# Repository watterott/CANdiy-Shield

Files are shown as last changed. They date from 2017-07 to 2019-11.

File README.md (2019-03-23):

# CANdiy-Shield
The CANdiy-Shield is a plug-on module for Arduino with CAN-Bus (Controller Area Network) connectivity.

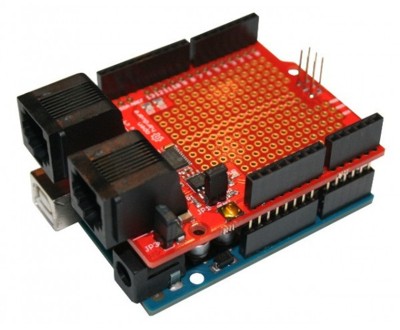
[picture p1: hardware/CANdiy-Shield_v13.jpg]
CANdiy-Shield


* Microchip CAN Controller (SPI)
* Microchip CAN Transceiver
* Switchable between 3V3 or 5V logic level (only CANdiy-Shield v2)
* 2 CAN connectors (RJ45)
* Prototyping Area
* Compatible with all Arduino Boards (SPI connection via 6-Pin ISP connector)
* Open-Source and released under the [Creative Commons Attribution Share-Alike License](https://creativecommons.org/licenses/by-sa/4.0/).
* **[Documentation on learn.watterott.com](https://learn.watterott.com)**

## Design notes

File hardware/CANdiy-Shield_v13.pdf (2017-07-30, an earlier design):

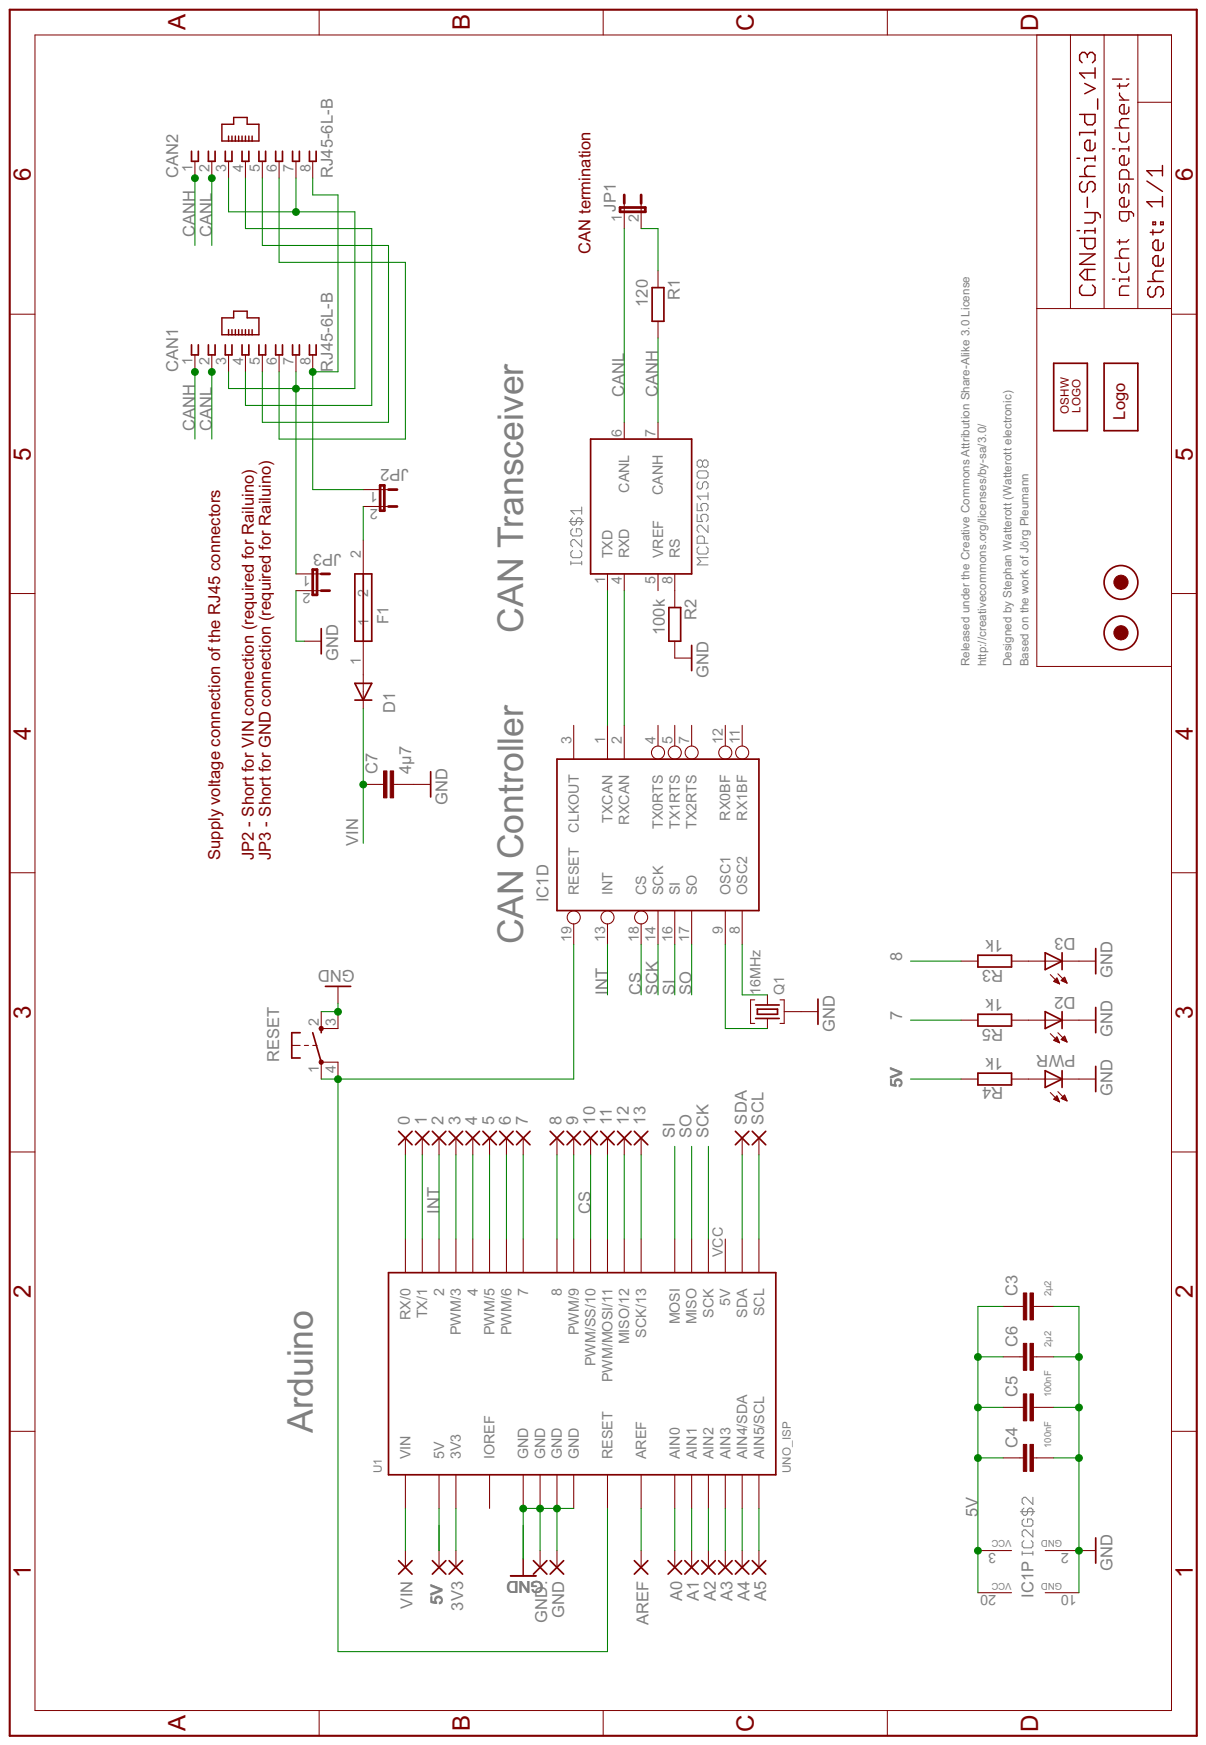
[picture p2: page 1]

Released under the Creative Commons Attribution Share-Alike 3.0 License

CAN Controller CAN Transceiver

Designed by Stephan Watterott (Watterott electronic)

http://creativecommons.org/licenses/by-sa/3.0/

JP2 - Short for VIN connection (required for Railuino)

JP3 - Short for GND connection (required for Railuino)

Based on the work of Jörg Pleumann

Supply voltage connection of the RJ45 connectors

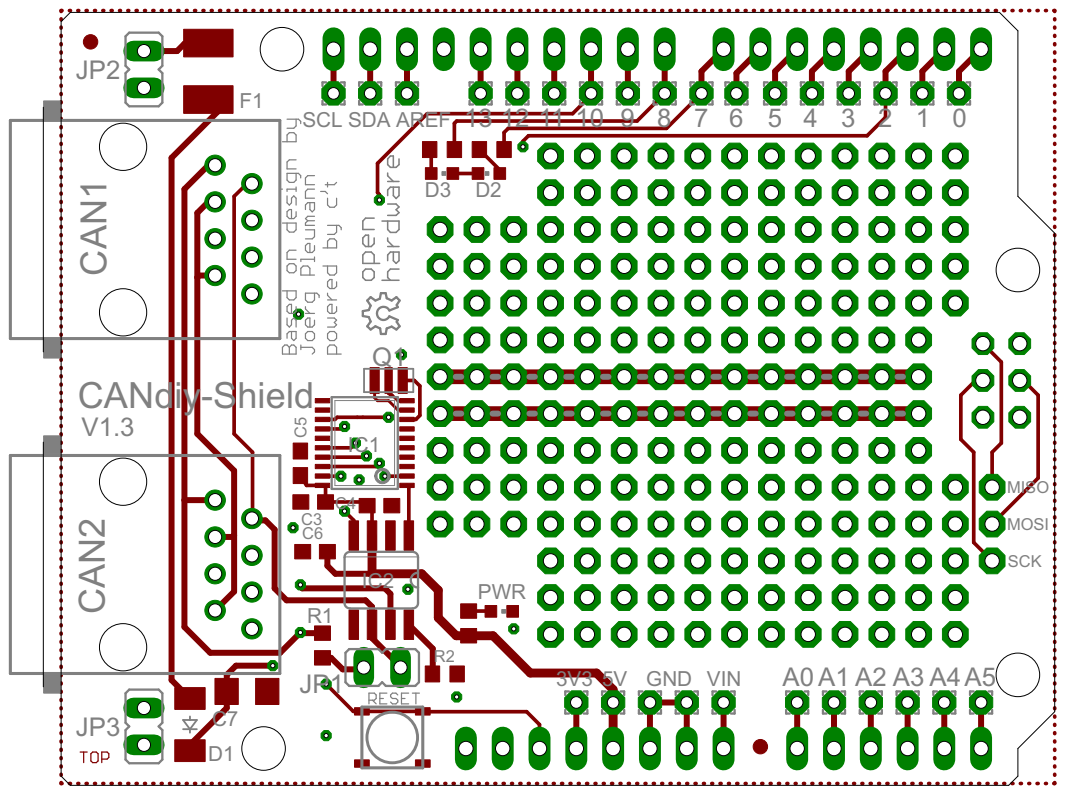
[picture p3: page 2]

# How to solder the connectors

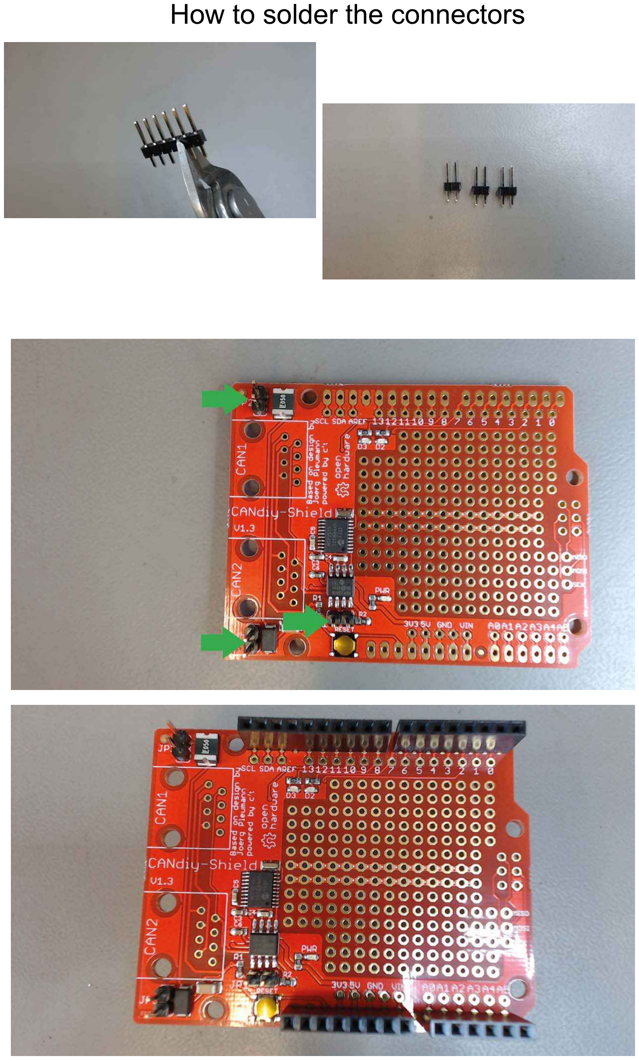
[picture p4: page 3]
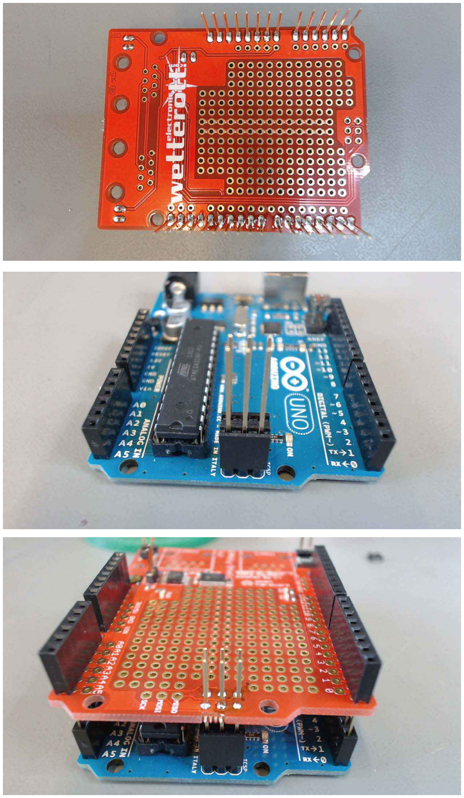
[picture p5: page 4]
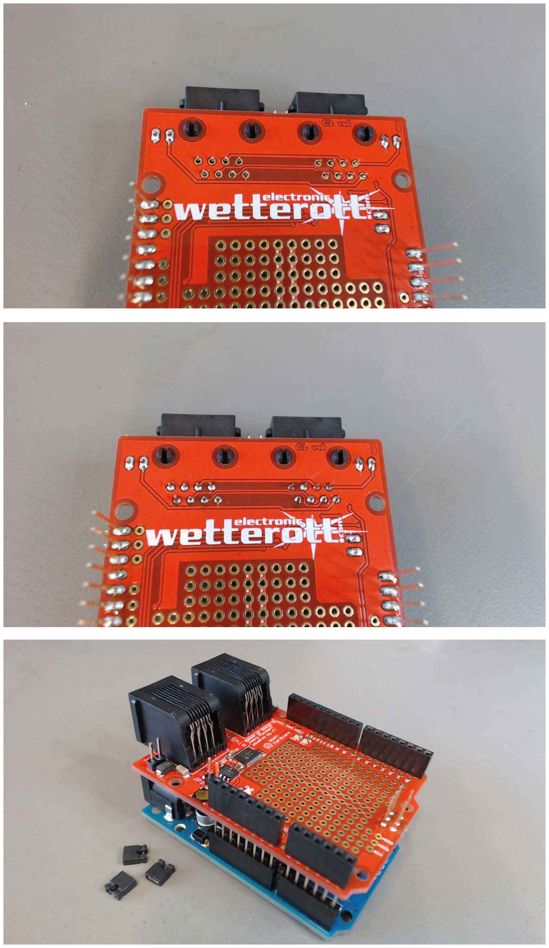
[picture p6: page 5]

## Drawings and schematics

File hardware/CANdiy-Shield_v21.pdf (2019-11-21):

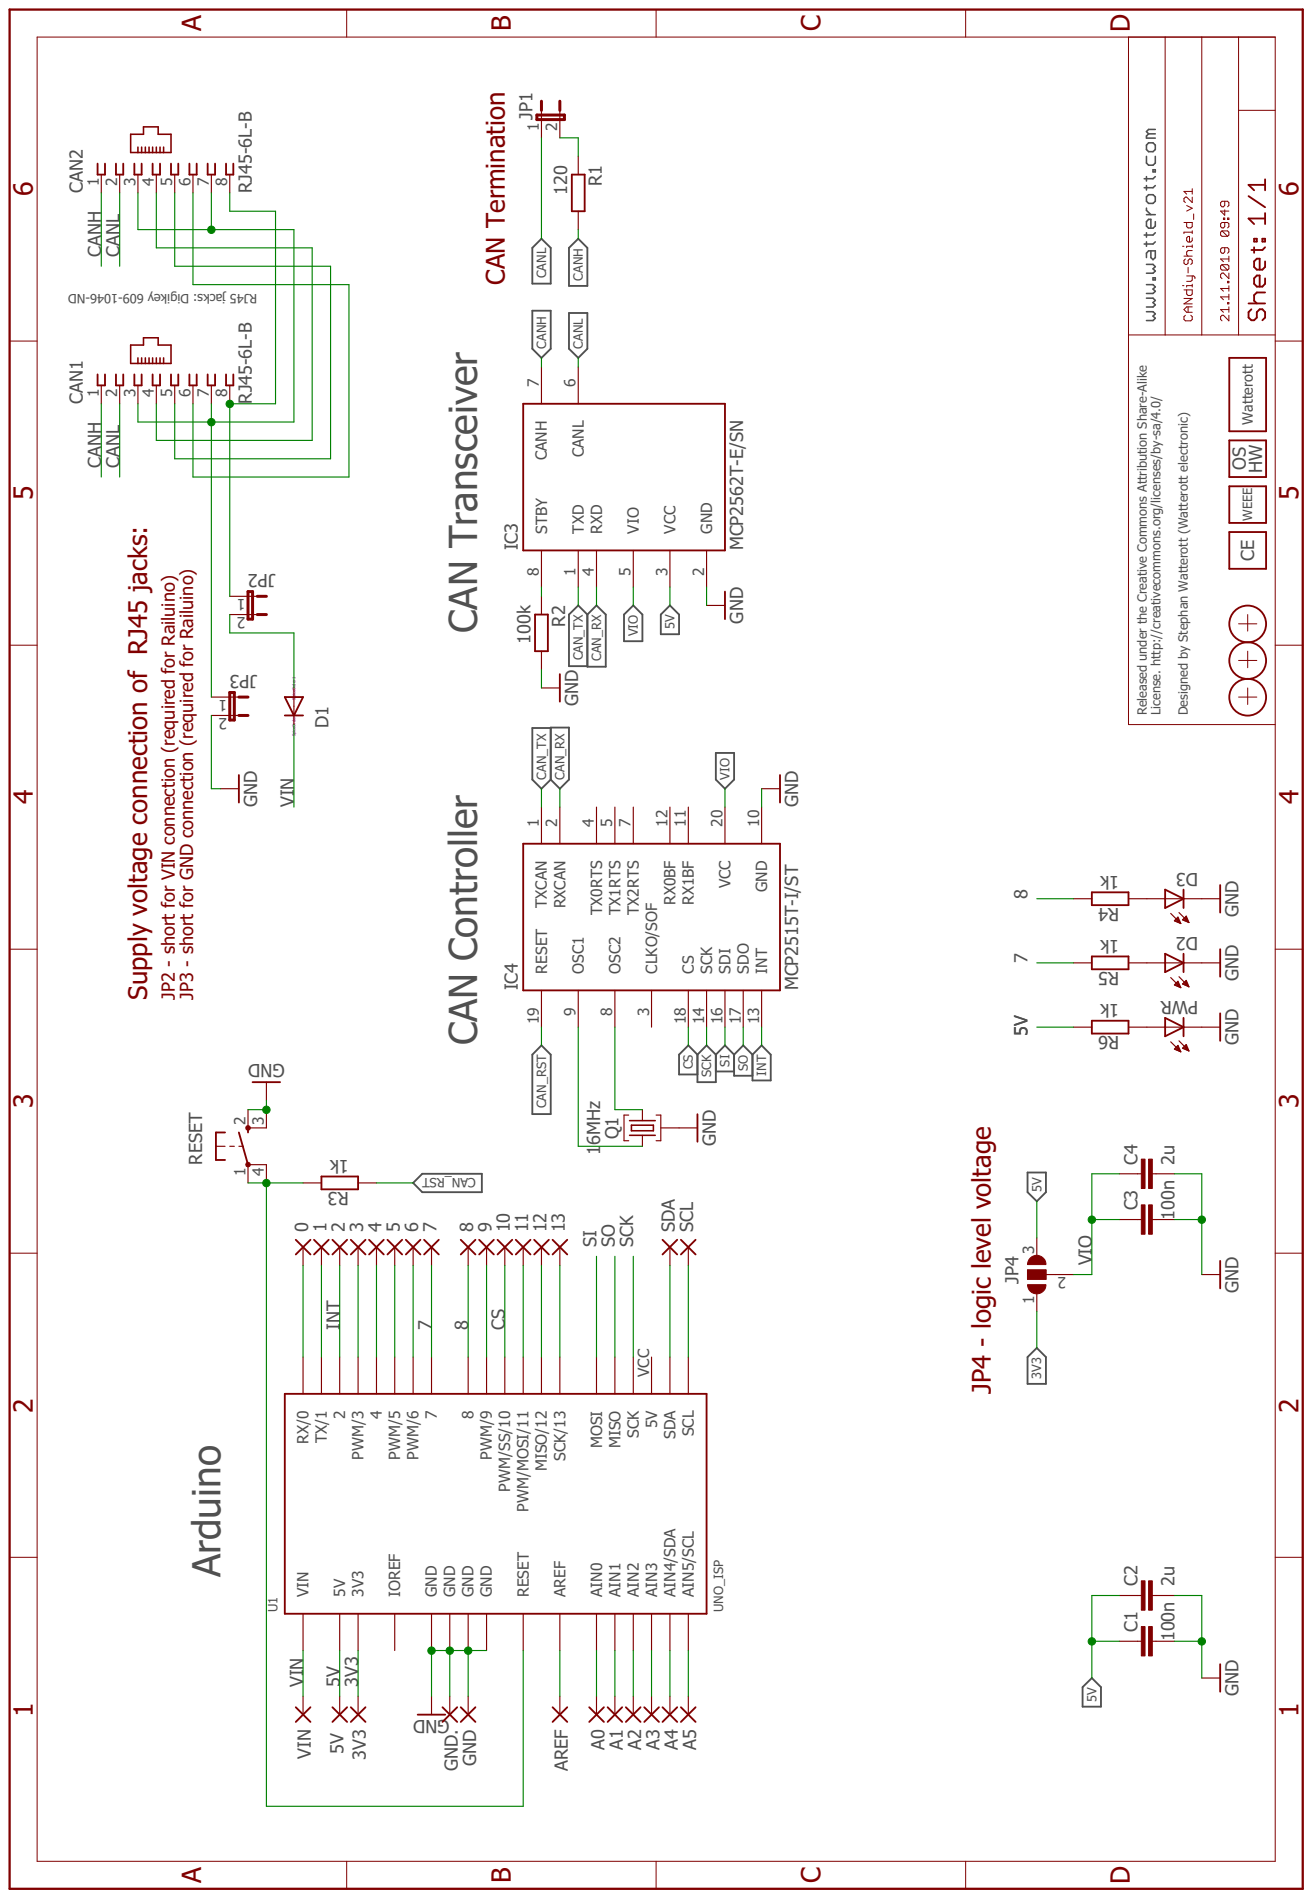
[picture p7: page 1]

SpiceOrder 1 SpiceOrder 2 DN- 6401- 906 yeki gi D:skcaj 54J RDNG DNG GND 120 RJ45-6L-B RJ45-6L-B 100n 2u GND 100k GND GND k1 GND k1 GND k1 GND 100n GND 2uk1 GND GND 16MHz Released under the Creative Commons Attribution Share-Alike License. http://creativecommons.org/licenses/by-sa/4.0/ Designed by Stephan Watterott (Watterott electronic) Arduino CAN Controller CAN Transceiver RESET 1 23 4 R1 CAN2 12345678 CAN1 12345678 C1 C2 R2 JP1 12 2PJ 123PJ 12 012345678910111213SDA SCL A0A1A2A3A4A5 AREF VIN GND GND. 3V3 3D 4R R WP 6R 2D 5R D1 U1UNO_ISP RX/0 TX/12 AIN0 PWM/34 PWM/5 PWM/678 PWM/9 PWM/SS/10 PWM/MOSI/11 MISO/12 SCK/13 AIN1 AIN2 AIN3 AIN4/SDA AIN5/SCL 5VVIN 3V3 AREF RESET SDA SCL IOREF GND GND GND MOSI MISO SCK GND 5V VCC C3 3 1 2 JP4 C4 3R Watterott CE OS HW WEEE IC3 MCP2562T-E/SN CANH 7 TXD 1 RXD 4 VIO 5 CANL 6 GND 2 VCC 3 STBY 8 IC4 MCP2515T-I/ST CS 18 SCK 14 GND 10 VCC 20 RESET 19 SDI 16 SDO 17 OSC2 8 OSC1 9 TXCAN 1 RXCAN 2 CLKO/SOF 3 TX0RTS 4 TX1RTS 5 TX2RTS 7 RX0BF 12 RX1BF 11 INT 13 Q1 5V 5V 5V 5V 5V 5V VIN VIN CAN_RX CAN_RX CAN_TX CAN_TX CS CS SCK SCK SI SI SO SO CANCHANH CANH CANH CANL CANL CANL CANL 8 8 INT INT 3V3 3V3 7 7 VIO VIO VIO TSR_NAC CAN_RST CAN Termination Supply voltage connection of RJ45 jacks: JP3 - short for GND connection (required for Railuino) JP2 - short for VIN connection (required for Railuino) JP4 - logic level voltage ABCD 1 2 3 4 5 6 ABCD 1 2 3 4 5 6

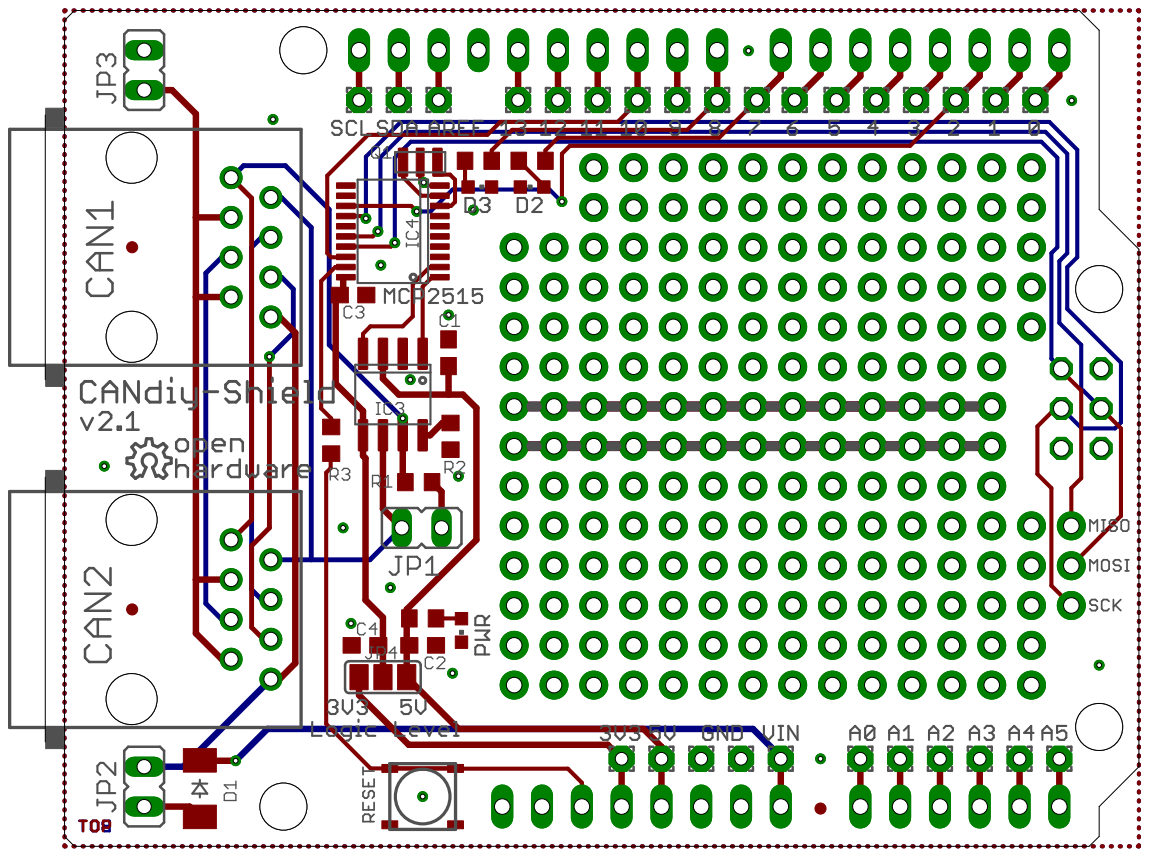
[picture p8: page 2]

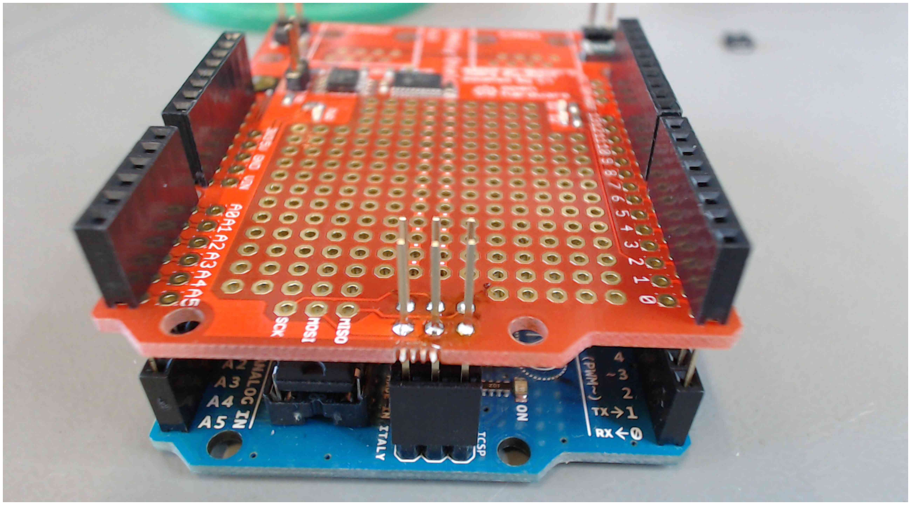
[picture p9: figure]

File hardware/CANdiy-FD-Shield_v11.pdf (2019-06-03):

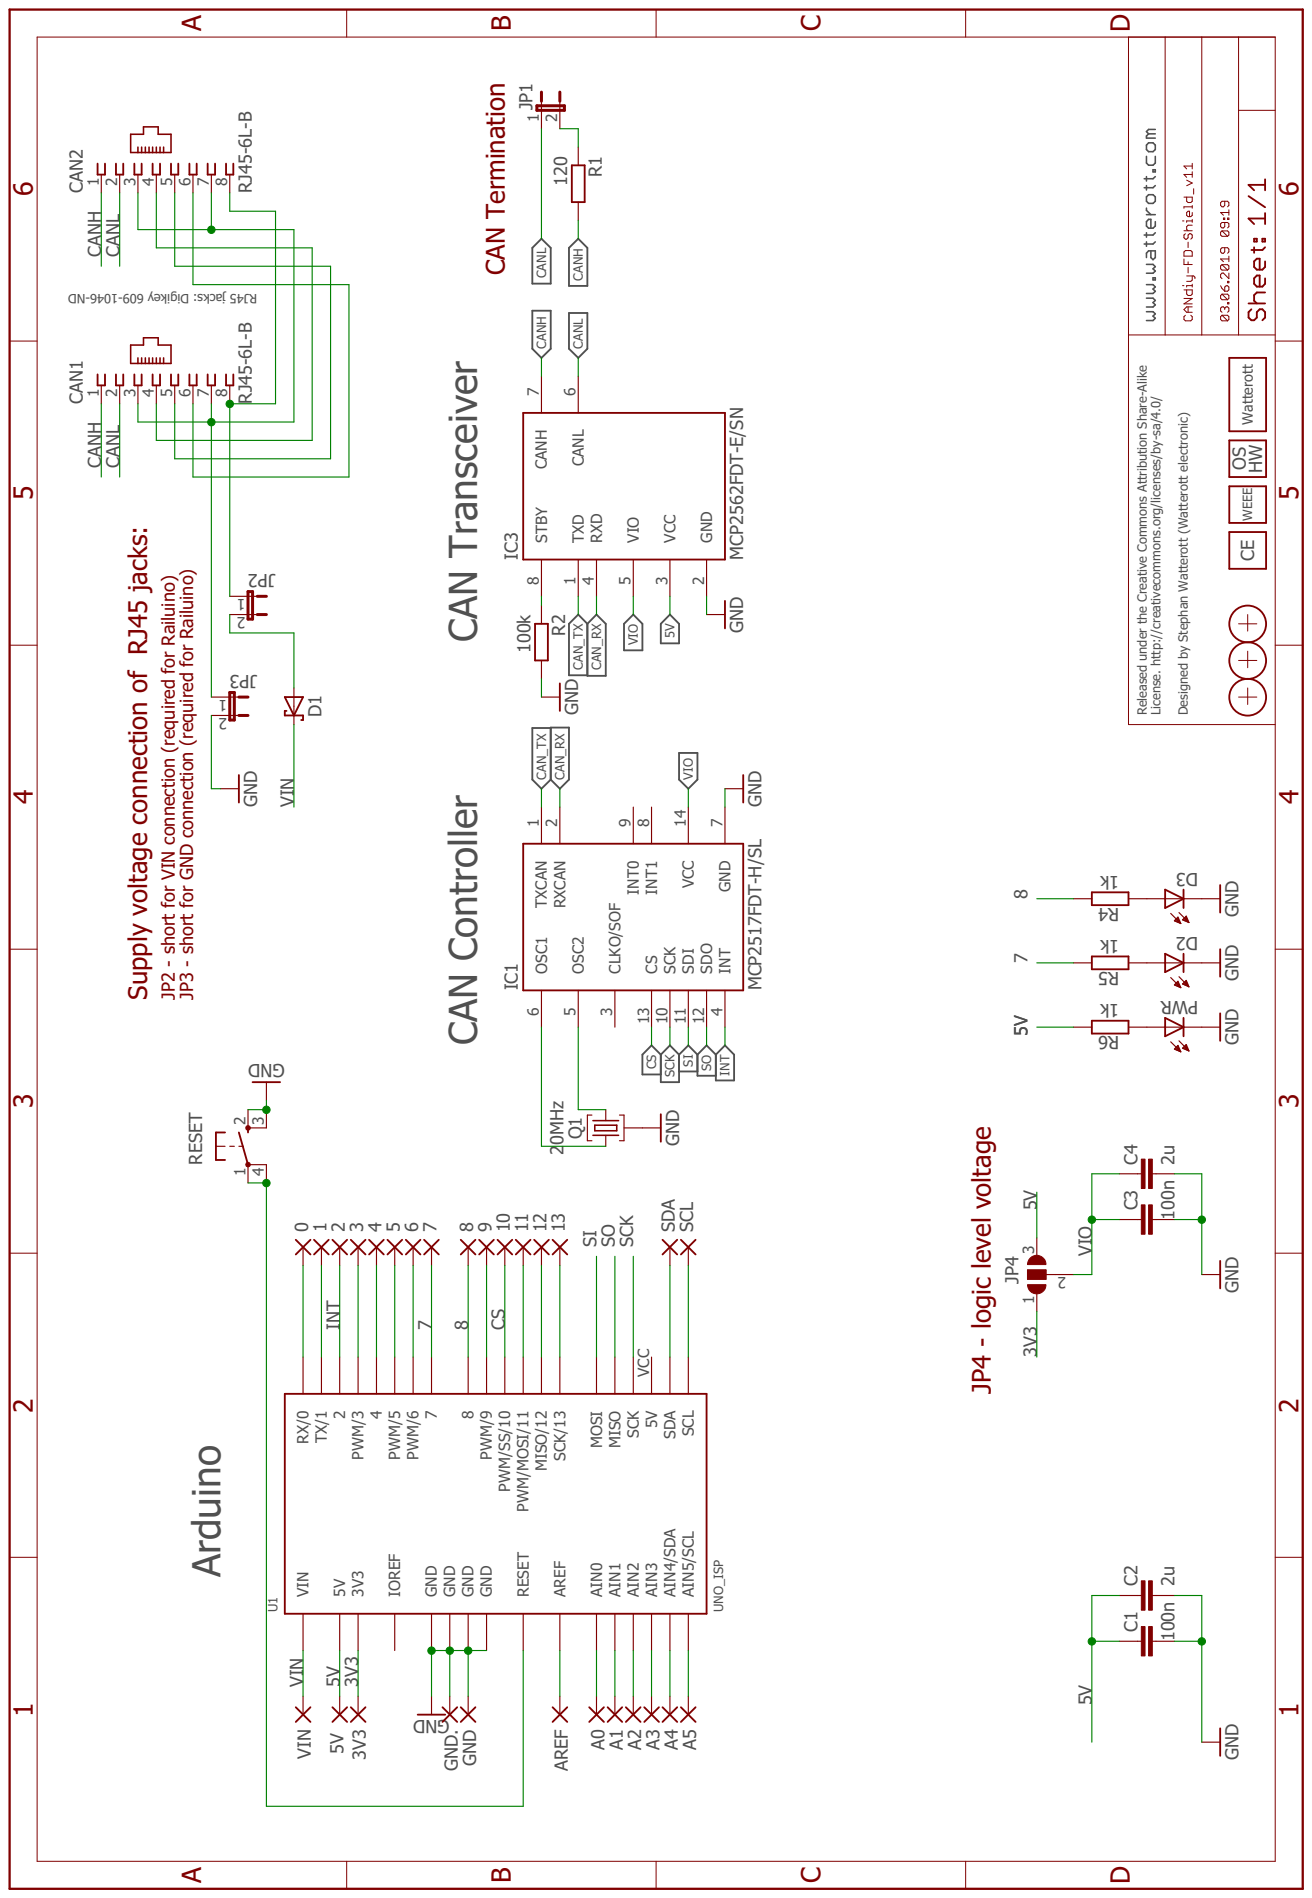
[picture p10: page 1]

DN- 6401- 906 yeki gi D:skcaj 54J RDNG DNG GND 120 RJ45-6L-B RJ45-6L-B 100n 2u GND 100k GND GND k1 GND k1 GND k1 GND 100n GND 2u GND GND 20MHz Released under the Creative Commons Attribution Share-Alike License. http://creativecommons.org/licenses/by-sa/4.0/ Designed by Stephan Watterott (Watterott electronic) Arduino CAN Controller CAN Transceiver RESET 1 23 4 R1 CAN2 12345678 CAN1 12345678 C1 C2 R2 JP1 12 2PJ 123PJ 12 012345678910111213SDA SCL A0A1A2A3A4A5 AREF VIN GND GND. 3V3 3D 4R R WP 6R 2D 5R U1UNO_ISP RX/0 TX/12 AIN0 PWM/34 PWM/5 PWM/678 PWM/9 PWM/SS/10 PWM/MOSI/11 MISO/12 SCK/13 AIN1 AIN2 AIN3 AIN4/SDA AIN5/SCL 5VVIN 3V3 AREF RESET SDA SCL IOREF GND GND GND MOSI MISO SCK GND 5V VCC C3 3 1 2 JP4 C4 Watterott CE OS HW WEEE IC3 MCP2562FDT-E/SN CANH 7 TXD 1 RXD 4 VIO 5 CANL 6 GND 2 VCC 3 STBY 8 IC1 MCP2517FDT-H/SL CS 13 SCK 10 GND 7 VCC 14 SDI 11 SDO 12 OSC2 5 OSC1 6 TXCAN 1 RXCAN 2 CLKO/SOF 3 INT0 9 INT1 8 INT 4 Q1 D1 5V 5V 5V 5V 5V 5V VIN VIN CAN_RX CAN_RX CAN_TX CAN_TX CS CS SCK SCK SI SI SO SO CANCHANH CANH CANH CANL CANL CANL CANL 8 8 INT INT 3V3 3V3 7 7 VIO VIO VIO CAN Termination Supply voltage connection of RJ45 jacks: JP3 - short for GND connection (required for Railuino) JP2 - short for VIN connection (required for Railuino) JP4 - logic level voltage ABCD 1 2 3 4 5 6 ABCD 1 2 3 4 5 6

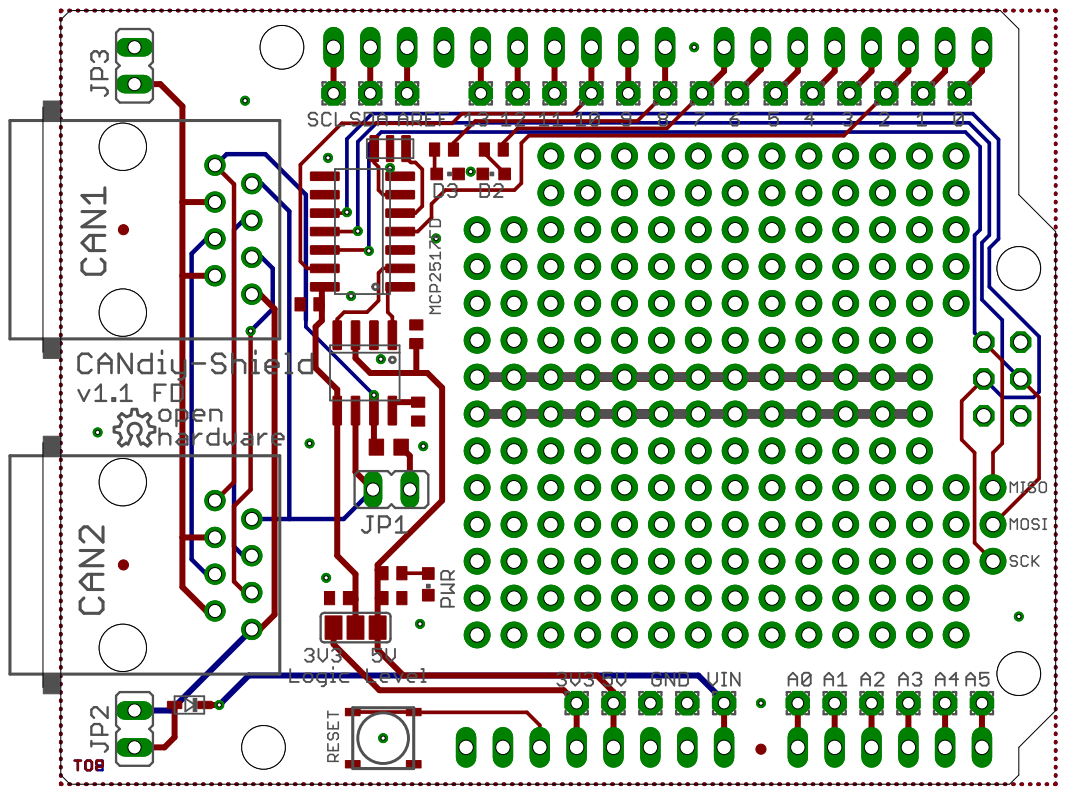
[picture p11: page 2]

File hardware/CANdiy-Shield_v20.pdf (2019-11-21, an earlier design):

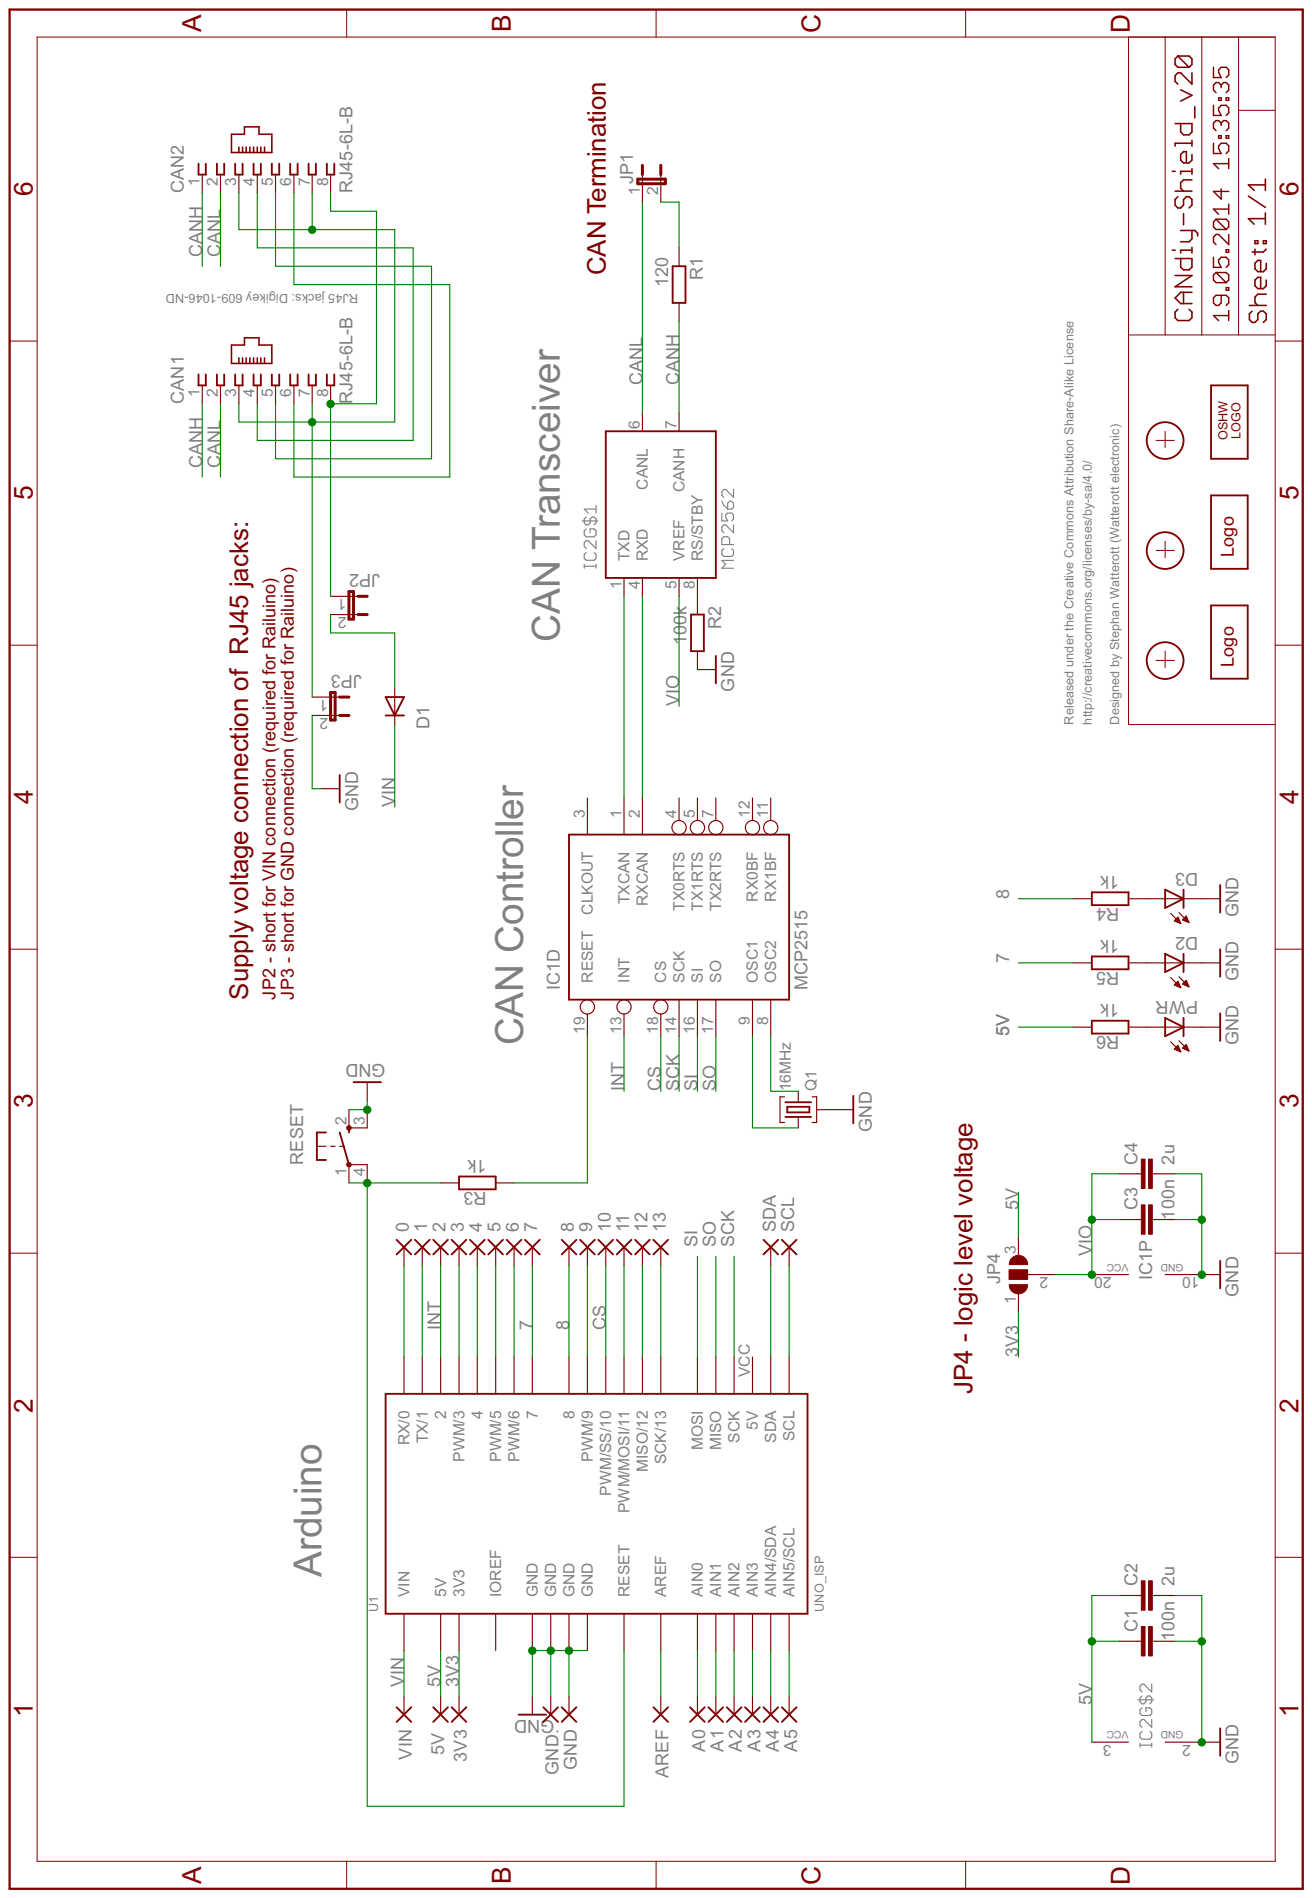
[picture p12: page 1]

DN- 6401- 906 yeki gi D: skcaj 54J RDNG DNG GND 120 RJ45-6L-B RJ45-6L-B 100n 2u GND 100k GND GNDk1 GNDk1 GNDk1 GND 16MHz MCP2515 100n GND 2uk1 Released under the Creative Commons Attribution Share-Alike License http://creativecommons.org/licenses/by-sa/4.0/ Designed by Stephan Watterott (Watterott electronic) Arduino CAN Controller CAN Transceiver /STBY RESET 1 23 4 CANH 7 CANL 6 RS 8 RXD 4 TXD 1 VREF 5 CCV DNG 3 2 R1 CAN2 12345678 CAN1 12345678 C1 C2 R2 JP1 12 2PJ 123PJ 12 012345678910111213SDA SCL A0A1A2A3A4A5 AREF VIN GND GND. 3V3 3D 4R R WP 6R 2D 5R D1 U1 UNO_ISP RX/0 TX/12 AIN0 PWM/34 PWM/5 PWM/678 PWM/9 PWM/SS/10 PWM/MOSI/11 MISO/12 SCK/13 AIN1 AIN2 AIN3 AIN4/SDA AIN5/SCL 5VVIN 3V3 AREF RESET SDA SCL IOREF GND GND GND MOSI MISO SCK GND 5V VCC Q1 IC1D CLKOUT 3 CS 18 INT 13 OSC1 9 OSC2 8 RESET 19 RX0BF 12 RX1BF 11 RXCAN 2 SCK 14 SI 16 SO 17 TX0RTS 4 TX1RTS 5 TX2RTS 7 TXCAN 1 CCV DNG IC1P 02 01 C3 3 1 2 JP4 C4 3R 5V 5V 5V 5V 5V VIN VIN CS CS SCK SCK SI SI SO SO CANH CANH CANH CANL CANL CANL 8 8 INT INT 3V3 3V3 7 7 VIO VIO CAN Termination Supply voltage connection of RJ45 jacks: JP3 - short for GND connection (required for Railuino) JP2 - short for VIN connection (required for Railuino) JP4 - logic level voltage ABCD 1 2 3 4 5 6 ABCD 1 2 3 4 5 6 OSHW LOGO Logo Logo

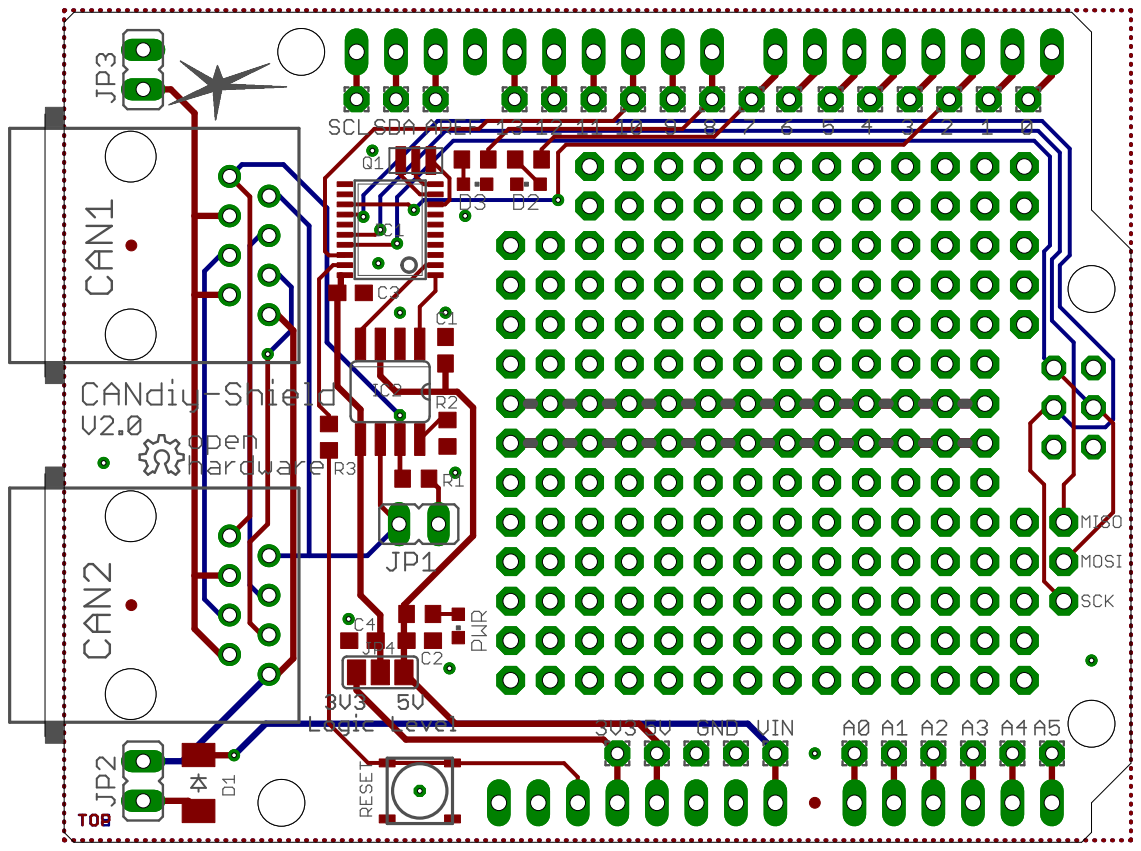
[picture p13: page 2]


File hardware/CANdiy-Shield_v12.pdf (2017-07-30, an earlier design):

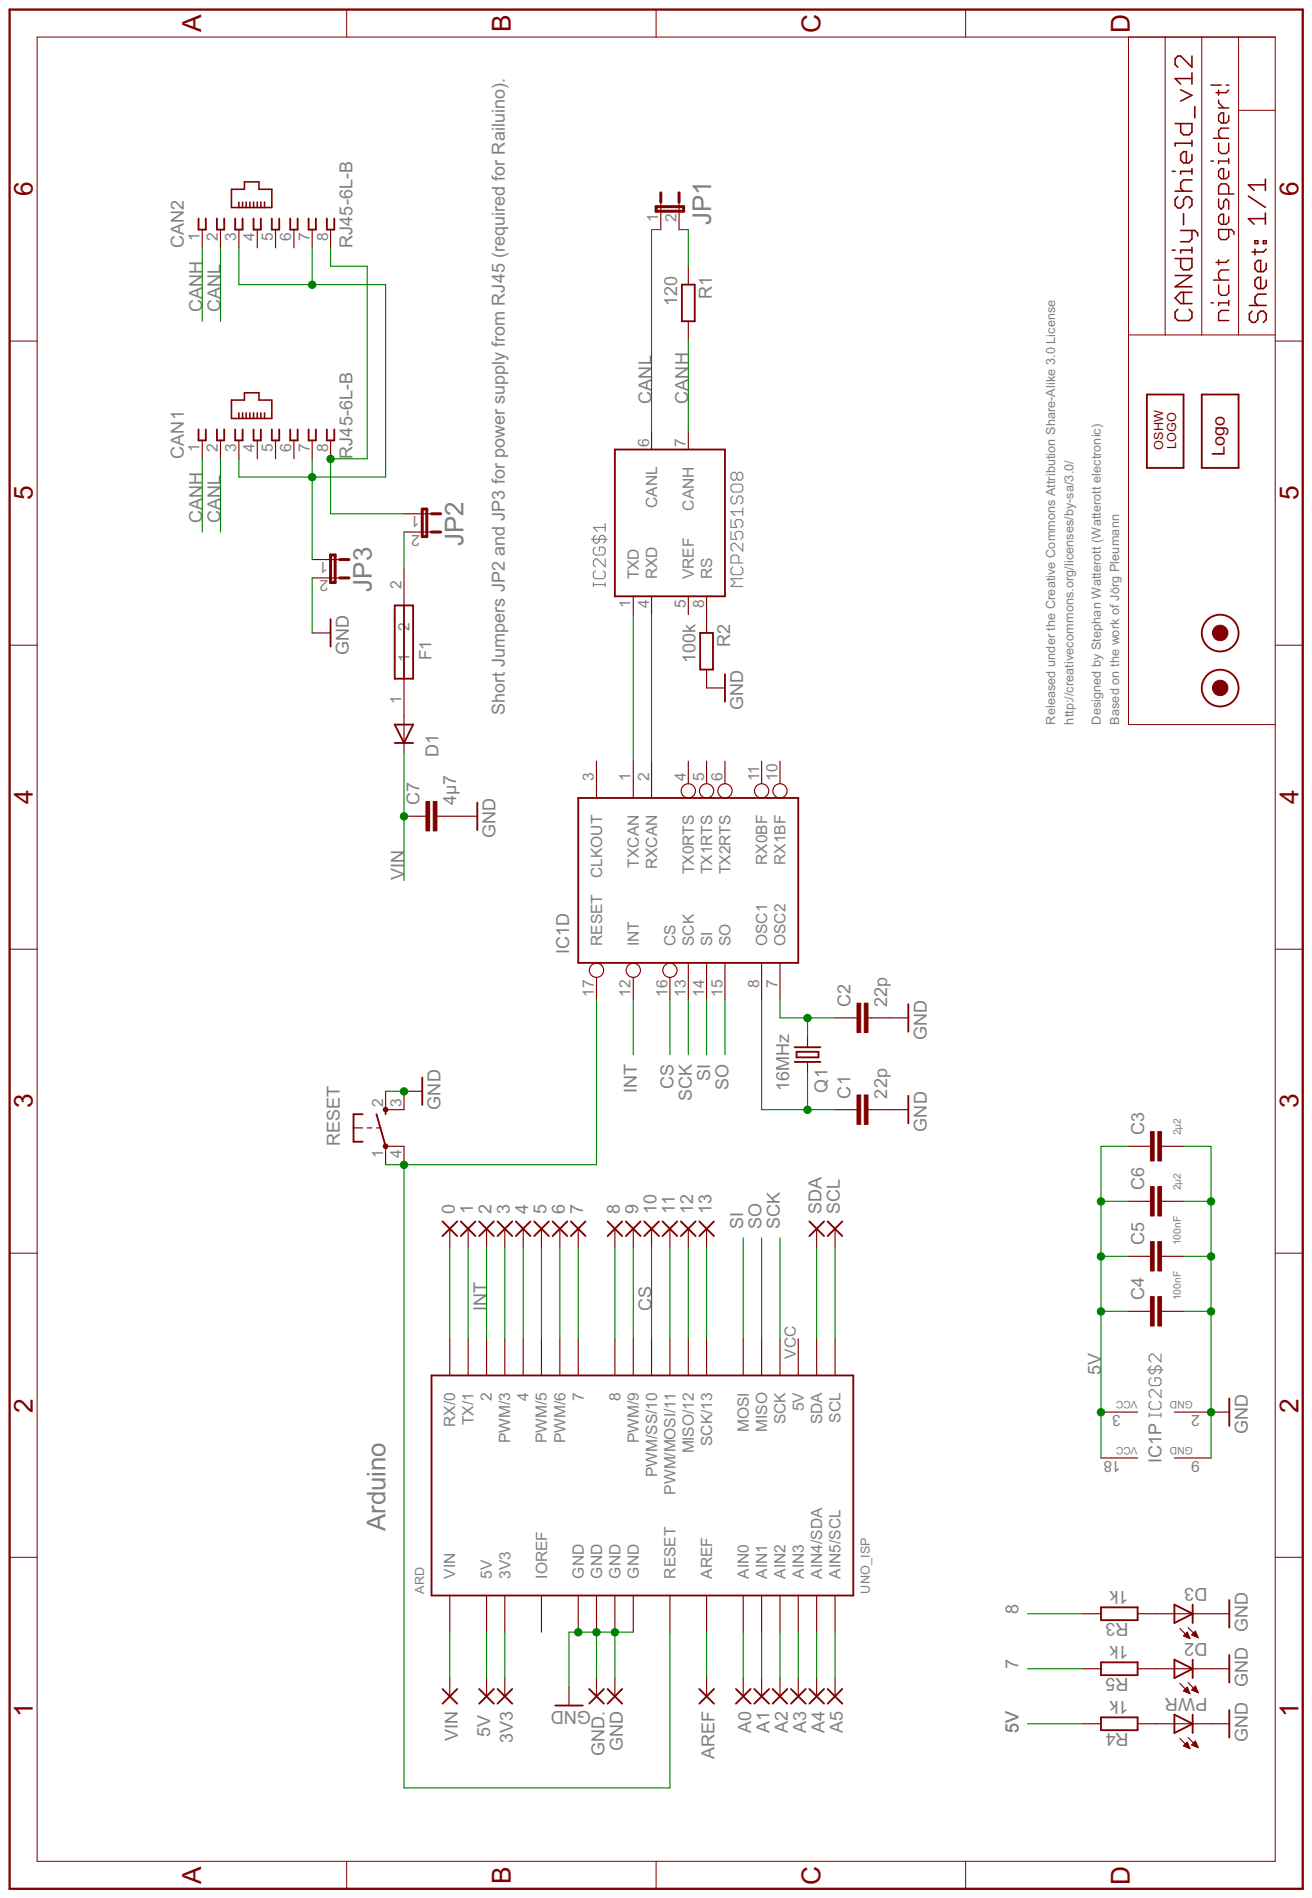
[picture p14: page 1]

GND GND 120 RJ45-6L-B RJ45-6L-B 16MHz 22p 22p 2µ2 100nF 100nF 2µ2 GND GND 100k GND DNG GNDk1 GNDk1 GNDk1 4µ7 GND GND Released under the Creative Commons Attribution Share-Alike 3.0 License http://creativecommons.org/licenses/by-sa/3.0/ Designed by Stephan Watterott (Watterott electronic) Arduino F1 Based on the work of Jörg Pleumann RESET 1 23 4 IC1D CLKOUT 3 CS 16 INT 12 OSC1 8 OSC2 7 RESET 17 RX0BF 11 RX1BF 10 RXCAN 2 SCK 13 SI 14 SO 15 TX0RTS 4 TX1RTS 5 TX2RTS 6 TXCAN 1 CANH 7 CANL 6 RS 8 RXD 4 TXD 1 VREF 5 CCV DNG 3 2 R1 CAN2 12345678 CAN1 12345678 Q1 C1 C2 C3 C4 C5 C6 CCV DNG IC1P 81 9 R2 12JP1 12 JP2 12 JP3 012345678910111213SDA SCL A0A1A2A3A4A5 AREF VIN GND GND. 3V3 3D 3R R WP 4R 2D 5R C7 D1 1 1 2 2 ARD UNO_ISP RX/0 TX/12 AIN0 PWM/34 PWM/5 PWM/678 PWM/9 PWM/SS/10 PWM/MOSI/11 MISO/12 SCK/13 AIN1 AIN2 AIN3 AIN4/SDA AIN5/SCL 5VVIN 3V3 AREF RESET SDA SCL IOREF GND GND GND MOSI MISO SCK GND 5V VCC 5V 5V 5V VIN CS CS SCK SCK SI SI SO SO CANH CANH CANH CANL CANL CANL 8 INT INT 7 ABCD 1 2 3 4 5 6 ABCD 1 2 3 4 5 6 OSHW LOGO Logo Short Jumpers JP2 and JP3 for power supply from RJ45 (required for Railuino).

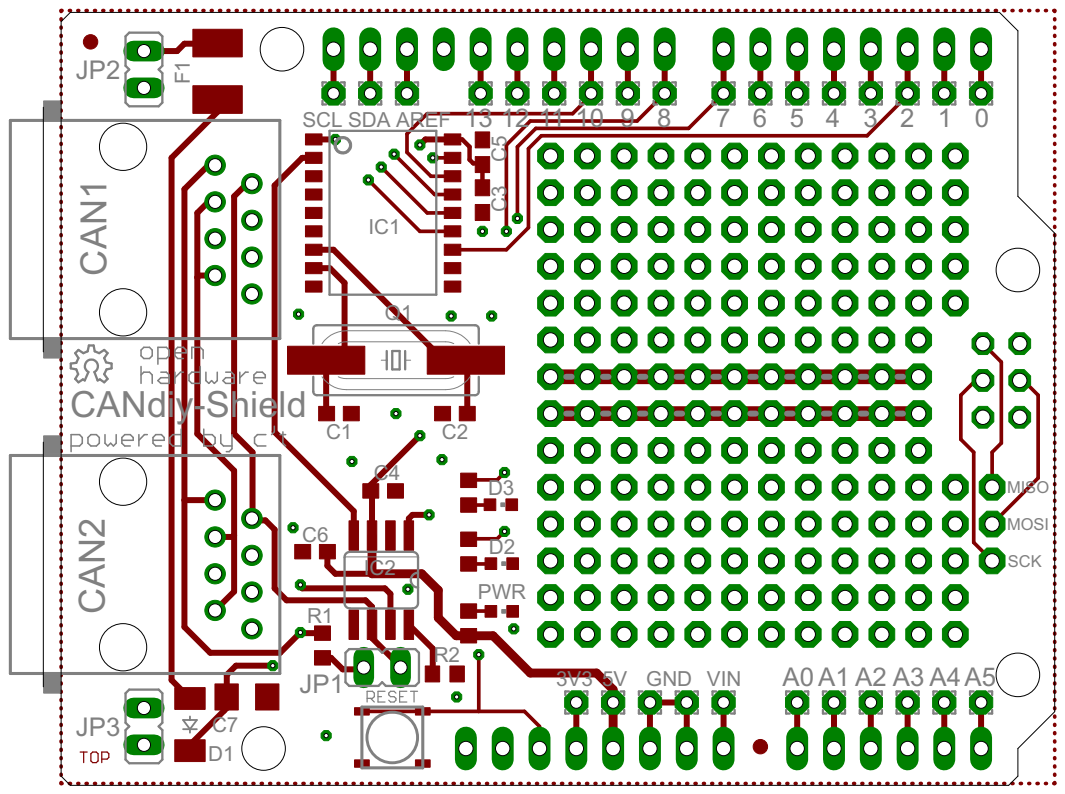
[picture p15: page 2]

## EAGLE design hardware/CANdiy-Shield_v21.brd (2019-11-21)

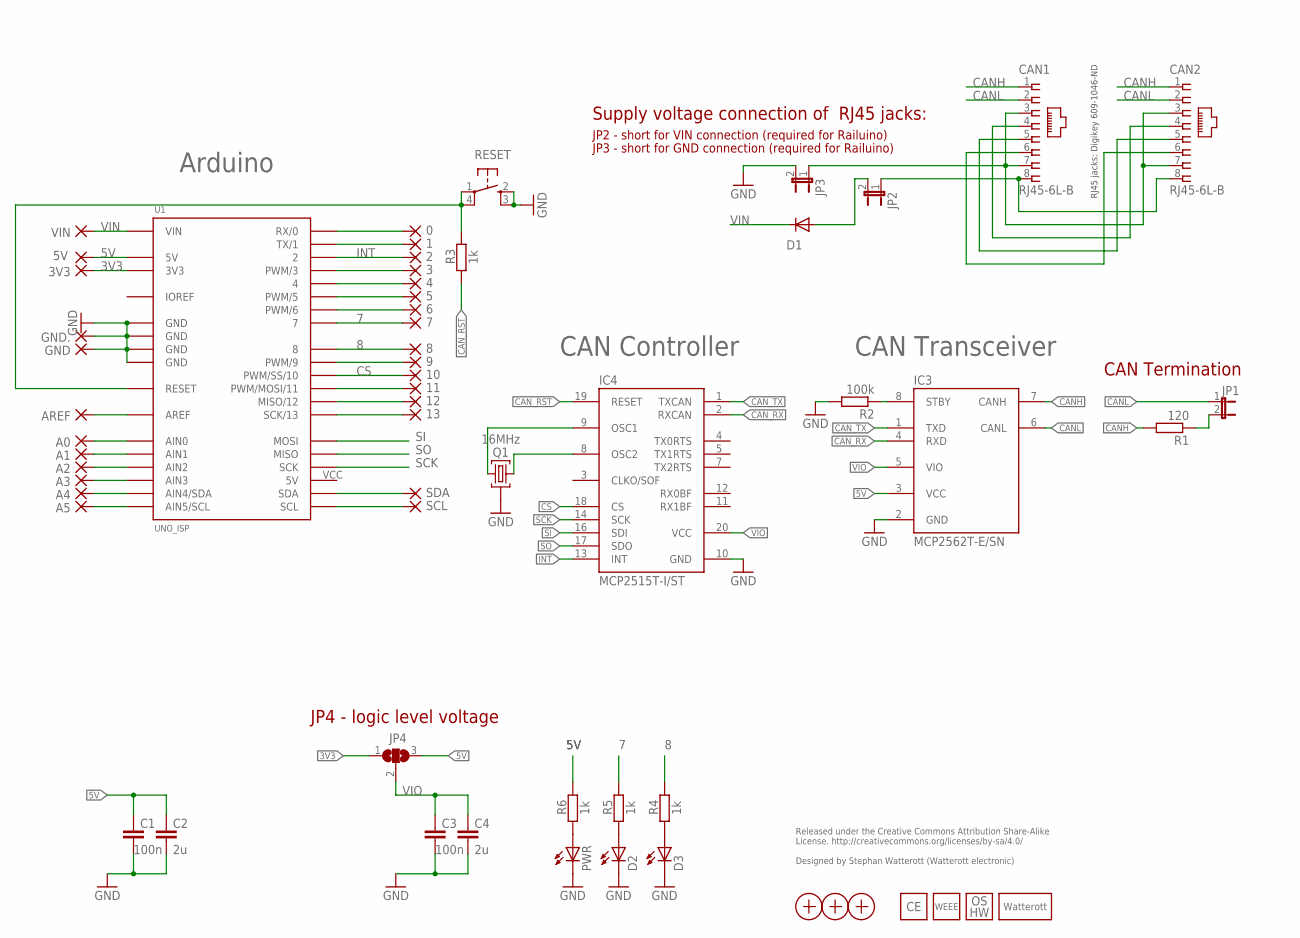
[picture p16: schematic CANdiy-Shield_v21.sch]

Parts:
0, 1, 2, 3, 3V3, 4, 5, 5V, 6, 7, 8, 9, 10, 11, 12, 13: 1,6/0,8
A0, A1, A2, A3, A4, A5: 1,6/0,8
AREF: 1,6/0,8
C1, C3: 100n; C0603
C2, C4: 2u; C0603
CAN1, CAN2: RJ45-6L-B; RJ45-NO-SHIELD
D1: CGRM4001-G; SOD-123_MINI-SMA
D2, D3: LEDCHIPLED_0603; CHIPLED_0603
GND, GND.: 1,6/0,8
IC3: MCP2562T-E/SN; SO08
IC4: MCP2515T-I/ST; TSSOP20
JP1, JP2, JP3: JP1E; JP1
JP4: SJ2W; SJ_2
LOGO3: LOGO-9; LOGO_9MM
LOGO4: LOGO_CE-2; CE_2MM
LOGO5: LOGO_OSHW-3; OSHW_3MM
LOGO6: LOGO_WEEE-4; WEEE_4MM
PWR: LEDCHIPLED_0603; CHIPLED_0603
Q1: 16MHz; CRYSTAL_32X13
R1: 120; R0603
R2: 100k; R0603
R3, R4, R5, R6: 1k; R0603
RESET: SW_SMDS; SW_SMD4
SCL: 1,6/0,8
SDA: 1,6/0,8
U1: UNO_ISP
VIN: 1,6/0,8
X1, X2, X3: PASSER-07; PASSER_07MM

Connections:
0: 0.1, U1.0 (RX/0)
1: 1.1, U1.1 (TX/1)
3: 3.1, U1.3 (PWM/3)
3V3: 3V3.1, JP4.1, U1.3V3
4: 4.1, U1.4
5: 5.1, U1.5 (PWM/5)
5V: 5V.1, C1.1, C2.1, IC3.3 (VCC), JP4.3, R6.1, U1.5V
6: 6.1, U1.6 (PWM/6)
7: 7.1, R5.1, U1.7
8: 8.1, R4.1, U1.8
9: 9.1, U1.9 (PWM/9)
11: 11.1, U1.11 (PWM/MOSI/11)
12: 12.1, U1.12 (MISO/12)
13: 13.1, U1.13 (SCK/13)
A0: A0.1, U1.AIN0
A1: A1.1, U1.AIN1
A2: A2.1, U1.AIN2
A3: A3.1, U1.AIN3
A4: A4.1, U1.AIN4 (AIN4/SDA)
A5: A5.1, U1.AIN5 (AIN5/SCL)
AREF: AREF.1, U1.AREF
CANH: CAN1.1, CAN2.1, IC3.7 (CANH), R1.2
CANL: CAN1.2, CAN2.2, IC3.6 (CANL), JP1.1
CAN_RST: IC4.19 (RESET), R3.2
CAN_RX: IC3.4 (RXD), IC4.2 (RXCAN)
CAN_TX: IC3.1 (TXD), IC4.1 (TXCAN)
CS: 10.1, IC4.18 (CS), U1.10 (PWM/SS/10)
GND: C1.2, C2.2, C3.2, C4.2, D2.C, D3.C, GND.1, GND..1, IC3.2 (GND), IC4.10 (GND), JP3.2, PWR.C, Q1.GND, R2.2, RESET.2 (S), RESET.3 (S1), U1.GND@1 (GND), U1.GND@2 (GND), U1.GND@3 (GND), U1.GND@4 (GND)
INT: 2.1, IC4.13 (INT), U1.2
IOREF: U1.IOREF
unnamed: CAN1.8, CAN2.8, JP2.1
unnamed: IC3.8 (STBY), R2.1
unnamed: CAN1.3, CAN1.7, CAN2.3, CAN2.7, JP3.1
unnamed: JP1.2, R1.1
unnamed: SCL.1, U1.SCL
unnamed: SDA.1, U1.SDA
unnamed: D3.A, R4.2
unnamed: PWR.A, R6.2
unnamed: D2.A, R5.2
unnamed: D1.A, JP2.2
unnamed: CAN1.4, CAN2.4
unnamed: CAN1.5, CAN2.5
unnamed: CAN1.6, CAN2.6
OSC1: IC4.9 (OSC1), Q1.2
OSC2: IC4.8 (OSC2), Q1.1
RESET: R3.1, RESET.1, RESET.4 (P1), U1.RST (RESET)
SCK: IC4.14 (SCK), U1.SCK
SI: IC4.16 (SDI), U1.MOSI
SO: IC4.17 (SDO), U1.MISO
VIN: D1.C, U1.VIN, VIN.1
VIO: C3.1, C4.1, IC3.5 (VIO), IC4.20 (VCC), JP4.2

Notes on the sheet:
Released under the Creative Commons Attribution Share-Alike License. http://creativecommons.org/licenses/by-sa/4.0/ Designed by Stephan Watterott (Watterott electronic)
Arduino
CAN Termination
Supply voltage connection of RJ45 jacks:
JP3 - short for GND connection (required for Railuino)
JP2 - short for VIN connection (required for Railuino)
RJ45 jacks: Digikey 609-1046-ND
CAN Controller
CAN Transceiver
JP4 - logic level voltage

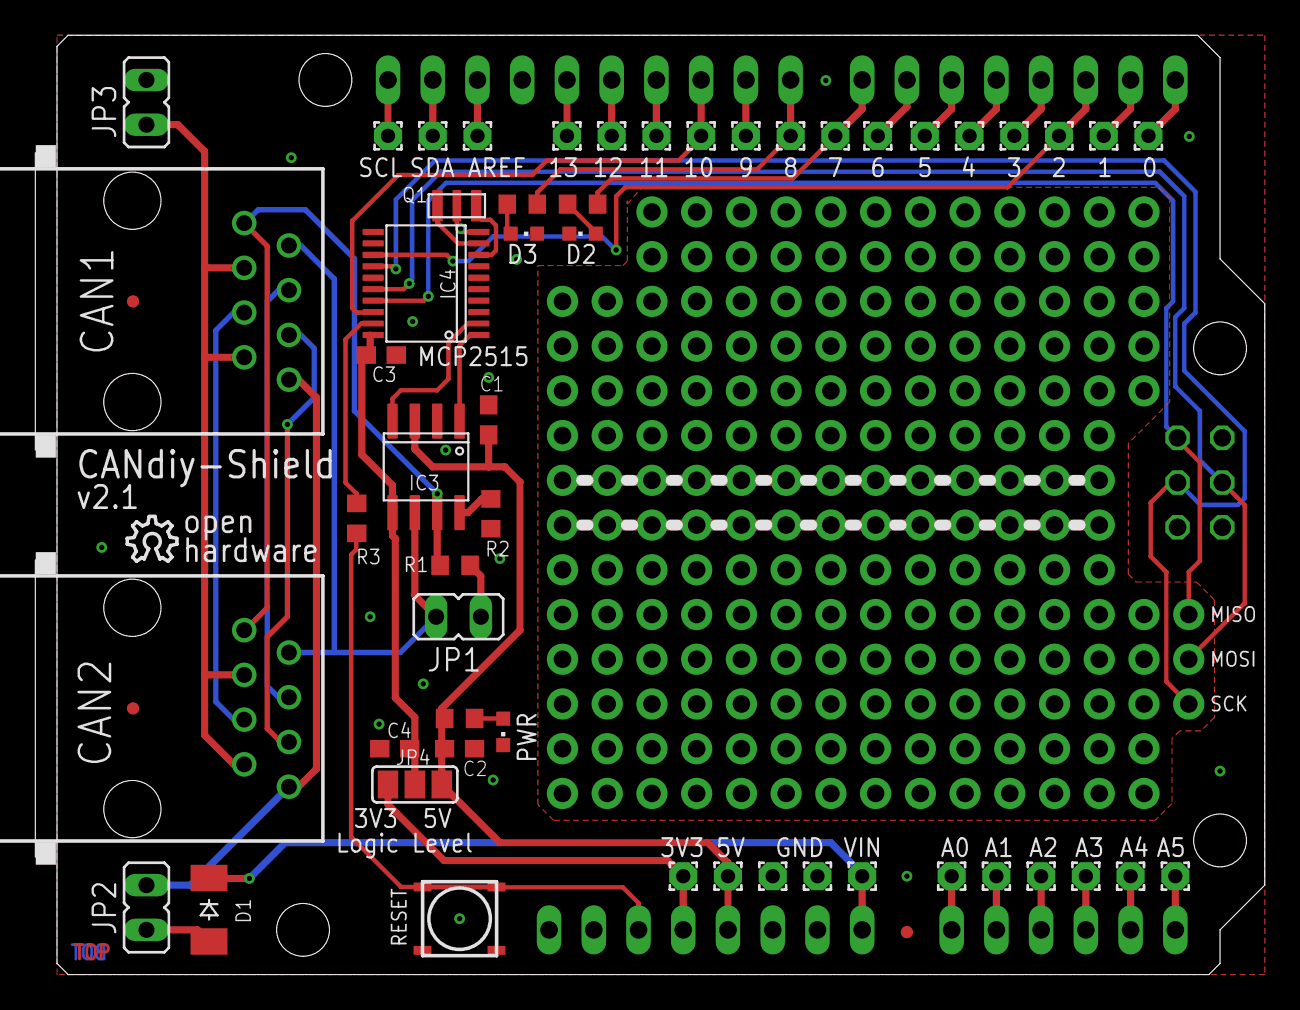
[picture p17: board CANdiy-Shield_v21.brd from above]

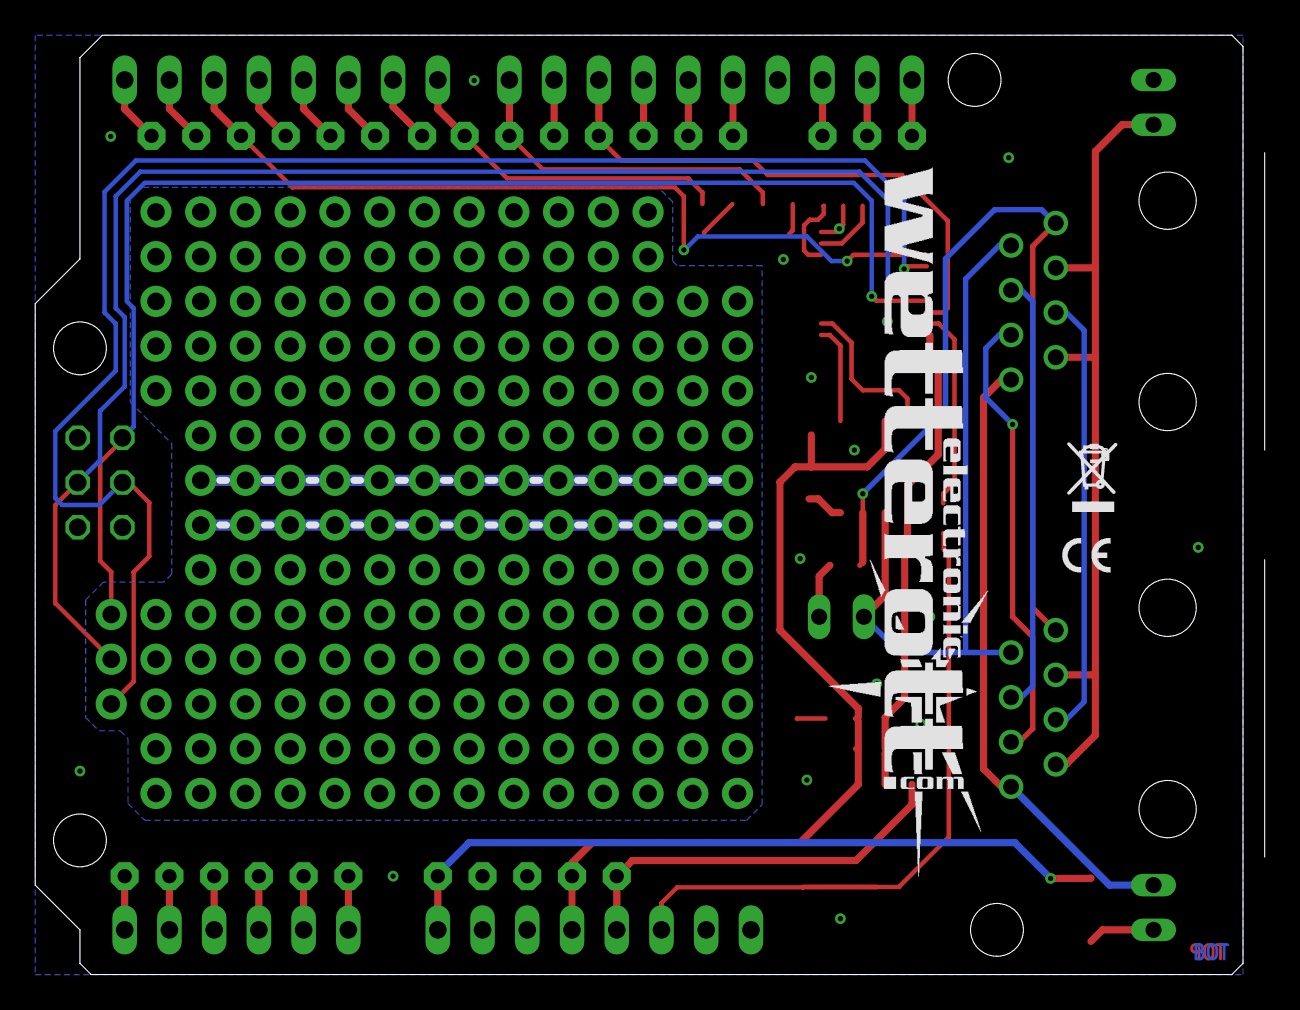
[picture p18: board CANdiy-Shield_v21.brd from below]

Board: 2 copper layers, 69.8 x 53.3 mm, 60 parts (3 on the bottom side), 50 nets.

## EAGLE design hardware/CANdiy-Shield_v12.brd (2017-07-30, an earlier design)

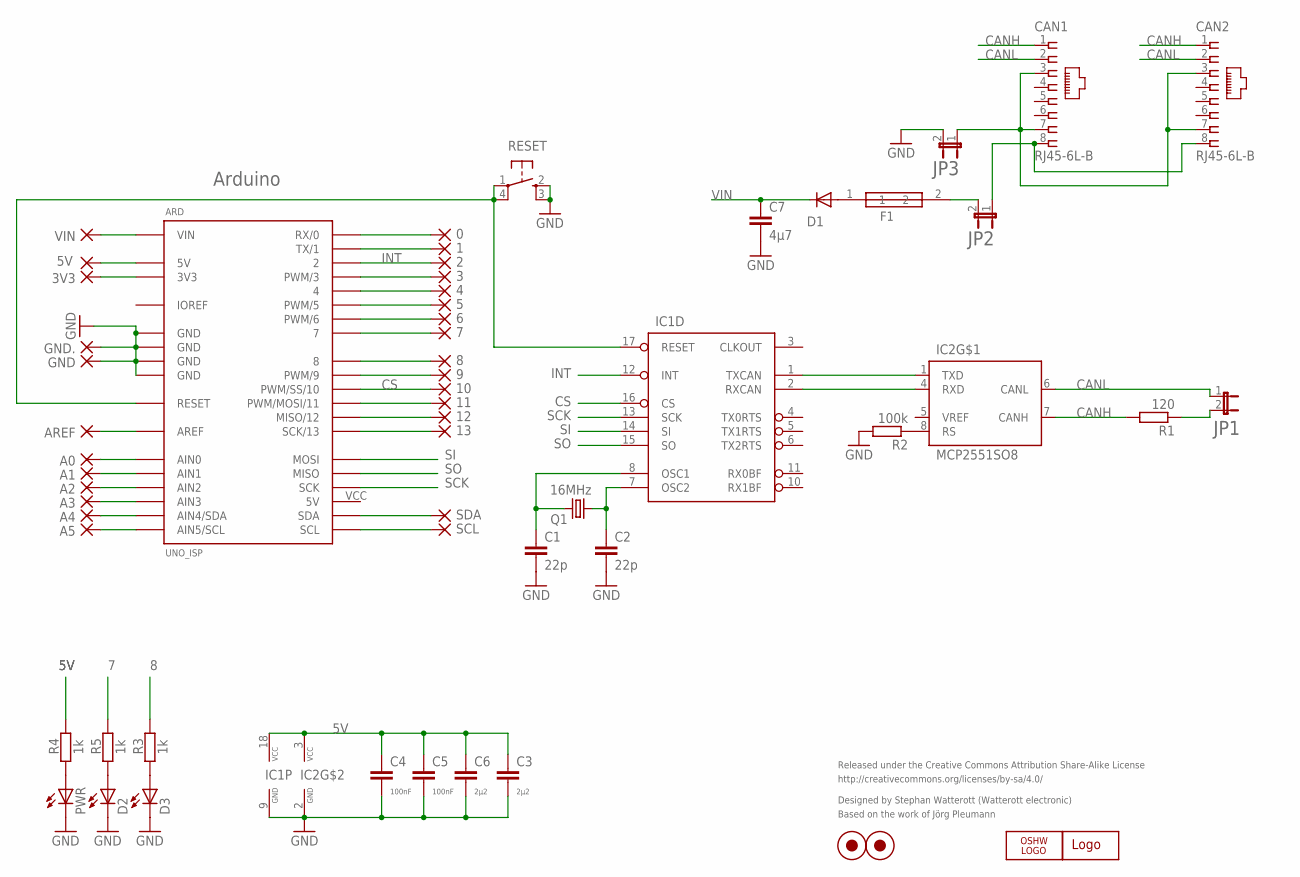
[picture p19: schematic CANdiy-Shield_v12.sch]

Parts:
0, 1, 2, 3, 3V3, 4, 5, 5V, 6, 7, 8, 9, 10, 11, 12, 13: 1,6/0,8
A0, A1, A2, A3, A4, A5: 1,6/0,8
ARD: UNO_ISP
AREF: 1,6/0,8
C1, C2: 22p; C0603
C3, C6: 2µ2; C0603
C4, C5: 100nF; C0603
C7: 4µ7; C1206
CAN1, CAN2: RJ45-6L-B; RJ45-NO-SHIELD
D1: CGRM4001-G; SOD-123_MINI-SMA
D2, D3: LEDCHIPLED_0603; CHIPLED_0603
F1: F1; L1812
GND, GND.: 1,6/0,8
IC1: MCP2515SO; SO-18W
IC2: MCP2551SO8; SO08
JP1, JP2, JP3: JP1E; JP1
LOGO2: OSHW_LOGO_6MILX0100-NT; OSHW_6X100_NOTEXT
PWR: LEDCHIPLED_0603; CHIPLED_0603
Q1: 16MHz; HC49UP
R1: 120; R0603
R2: 100k; R0603
R3, R4, R5: 1k; R0603
RESET: SW_SMDS; SW_SMD4
SCL: 1,6/0,8
SDA: 1,6/0,8
U$1: WE-LOGO
VIN: 1,6/0,8
X_1, X_2: PASS_1MM; ROUND_1MM

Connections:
3V3: 3V3.1, ARD.3V3
5V: 5V.1, ARD.5V, C3.1, C4.1, C5.1, C6.1, IC1.18 (VCC), IC2.3 (VCC), R4.1
7: 7.1, ARD.7, R5.1
8: 8.1, ARD.8, R3.1
9: 9.1, ARD.9 (PWM/9)
A0: A0.1, ARD.AIN0
AERF: ARD.AREF, AREF.1
CANH: CAN1.1, CAN2.1, IC2.7 (CANH), R1.2
CANL: CAN1.2, CAN2.2, IC2.6 (CANL), JP1.1
CS: 10.1, ARD.10 (PWM/SS/10), IC1.16 (CS)
GND: ARD.GND@1 (GND), ARD.GND@2 (GND), ARD.GND@3 (GND), ARD.GND@4 (GND), C1.2, C2.2, C3.2, C4.2, C5.2, C6.2, C7.2, D2.C, D3.C, GND.1, GND..1, IC1.9 (GND), IC2.2 (GND), JP3.2, PWR.C, R2.2, RESET.2 (S), RESET.3 (S1)
INT: 2.1, ARD.2, IC1.12 (INT)
IOREF: ARD.IOREF
unnamed: C2.1, IC1.7 (OSC2), Q1.1
unnamed: C1.1, IC1.8 (OSC1), Q1.2
unnamed: CAN1.8, CAN2.8, JP2.1
unnamed: IC2.8 (RS), R2.1
unnamed: CAN1.3, CAN1.7, CAN2.3, CAN2.7, JP3.1
unnamed: JP1.2, R1.1
unnamed: ARD.SCL, SCL.1
unnamed: ARD.SDA, SDA.1
unnamed: D3.A, R3.2
unnamed: PWR.A, R4.2
unnamed: D2.A, R5.2
unnamed: 11.1, ARD.11 (PWM/MOSI/11)
unnamed: 12.1, ARD.12 (MISO/12)
unnamed: 13.1, ARD.13 (SCK/13)
unnamed: 6.1, ARD.6 (PWM/6)
unnamed: 5.1, ARD.5 (PWM/5)
unnamed: 4.1, ARD.4
unnamed: 3.1, ARD.3 (PWM/3)
unnamed: 1.1, ARD.1 (TX/1)
unnamed: 0.1, ARD.0 (RX/0)
unnamed: A1.1, ARD.AIN1
unnamed: A2.1, ARD.AIN2
unnamed: A3.1, ARD.AIN3
unnamed: A4.1, ARD.AIN4 (AIN4/SDA)
unnamed: A5.1, ARD.AIN5 (AIN5/SCL)
unnamed: D1.A, F1.1
unnamed: F1.2, JP2.2
RESET: ARD.RST (RESET), IC1.17 (RESET), RESET.1, RESET.4 (P1)
RXCAN: IC1.2 (RXCAN), IC2.4 (RXD)
SCK: ARD.SCK, IC1.13 (SCK)
SI: ARD.MOSI, IC1.14 (SI)
SO: ARD.MISO, IC1.15 (SO)
TXCAN: IC1.1 (TXCAN), IC2.1 (TXD)
VIN: ARD.VIN, C7.1, D1.C, VIN.1

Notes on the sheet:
Released under the Creative Commons Attribution Share-Alike License
http://creativecommons.org/licenses/by-sa/4.0/
Designed by Stephan Watterott (Watterott electronic)
Arduino
Based on the work of Jörg Pleumann

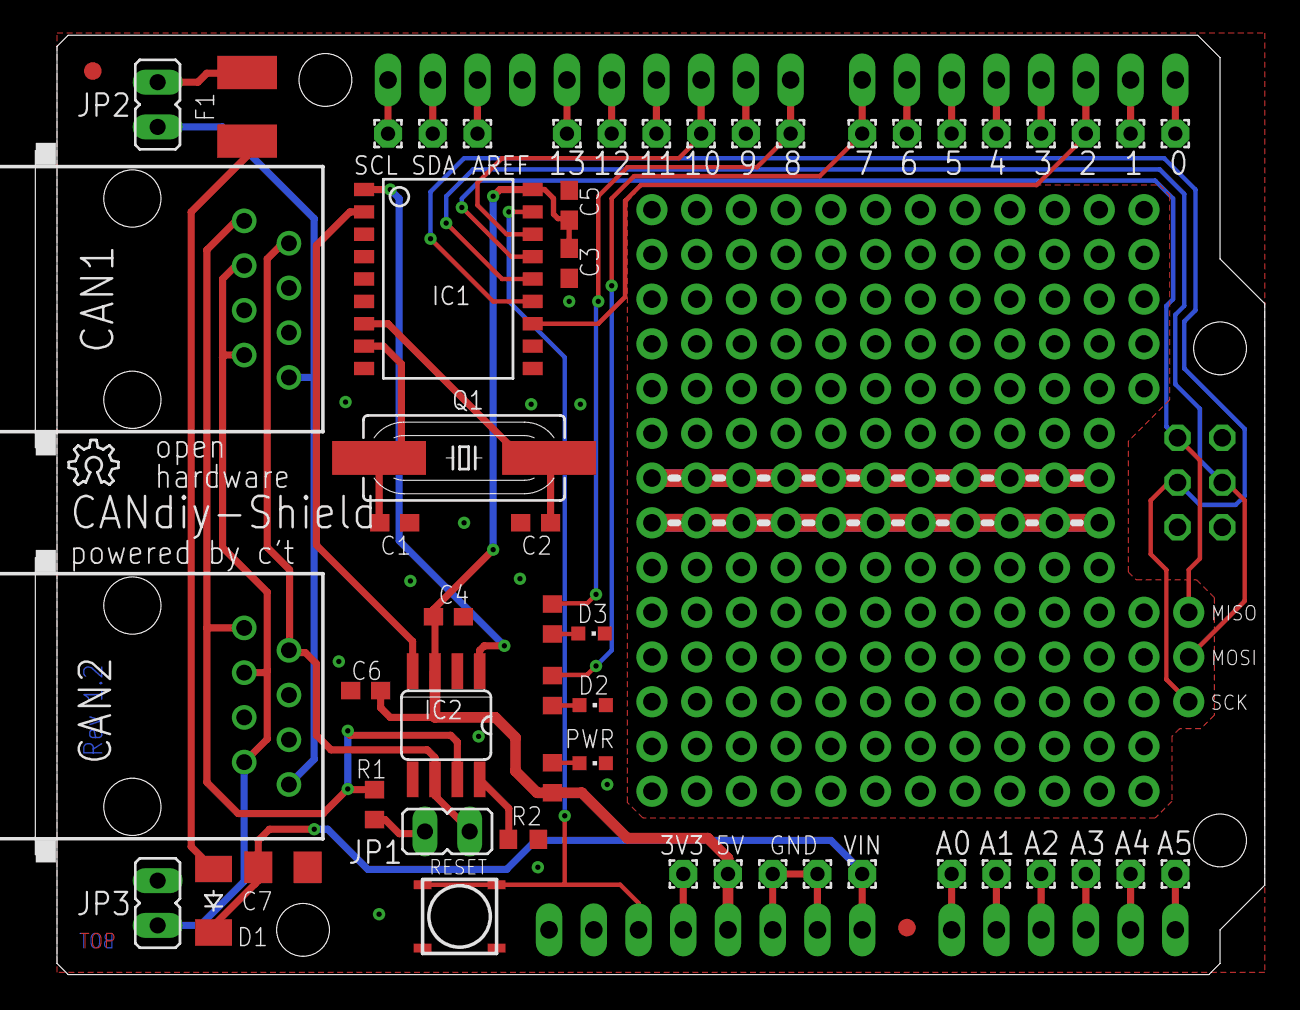
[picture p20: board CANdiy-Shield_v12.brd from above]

Board: 2 copper layers, 69.8 x 53.3 mm, 59 parts (1 on the bottom side), 46 nets.

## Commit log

2018-11-23 added CANdiy-FD v1.1
    [CANdiy-FD-Shield_v11.brd, CANdiy-FD-Shield_v11.sch]
2019-06-03 updated schematics
    [CANdiy-FD-Shield_v11.brd, CANdiy-FD-Shield_v11.sch]
2019-11-21 added rev 2.1
    [CANdiy-Shield_v21.brd, CANdiy-Shield_v21.sch]
